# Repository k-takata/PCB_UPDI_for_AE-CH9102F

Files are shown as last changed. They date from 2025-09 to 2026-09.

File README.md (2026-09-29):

# UPDI Adapter for AE-CH9102F (Rev. 2)

## 概要

[秋月電子](https://akizukidenshi.com/)の[CH9102F USBシリアル変換モジュールキット Type-C (AE-CH9102F-TYPEC-BO)](https://akizukidenshi.com/catalog/g/g129505/)を、AVRマイコンのUPDI (Unified Program and Debug Interface)書き込み装置として使うためのアダプターです。

UPDI書き込みモードとシリアル通信モードは自動的に切り替わります。(Rev. 2)

UPDI部分の回路は[SerialUPDI](https://github.com/SpenceKonde/AVR-Guidance/blob/master/UPDI/jtag2updi.md)の "No resistor on target OR adapter" の回路を元に、RTS信号による自動切り替え機能を追加してあります。

注: 本アダプターは高電圧(HV)プログラミングには対応していません。HVプログラミングが必要な場合は、関連プロジェクトの[UPDI Unbricker](https://github.com/k-takata/PCB_updi_unbricker)を参照してください。

## 使用したソフトウェア

KiCad 9.0

## 回路図

Rev. 2  
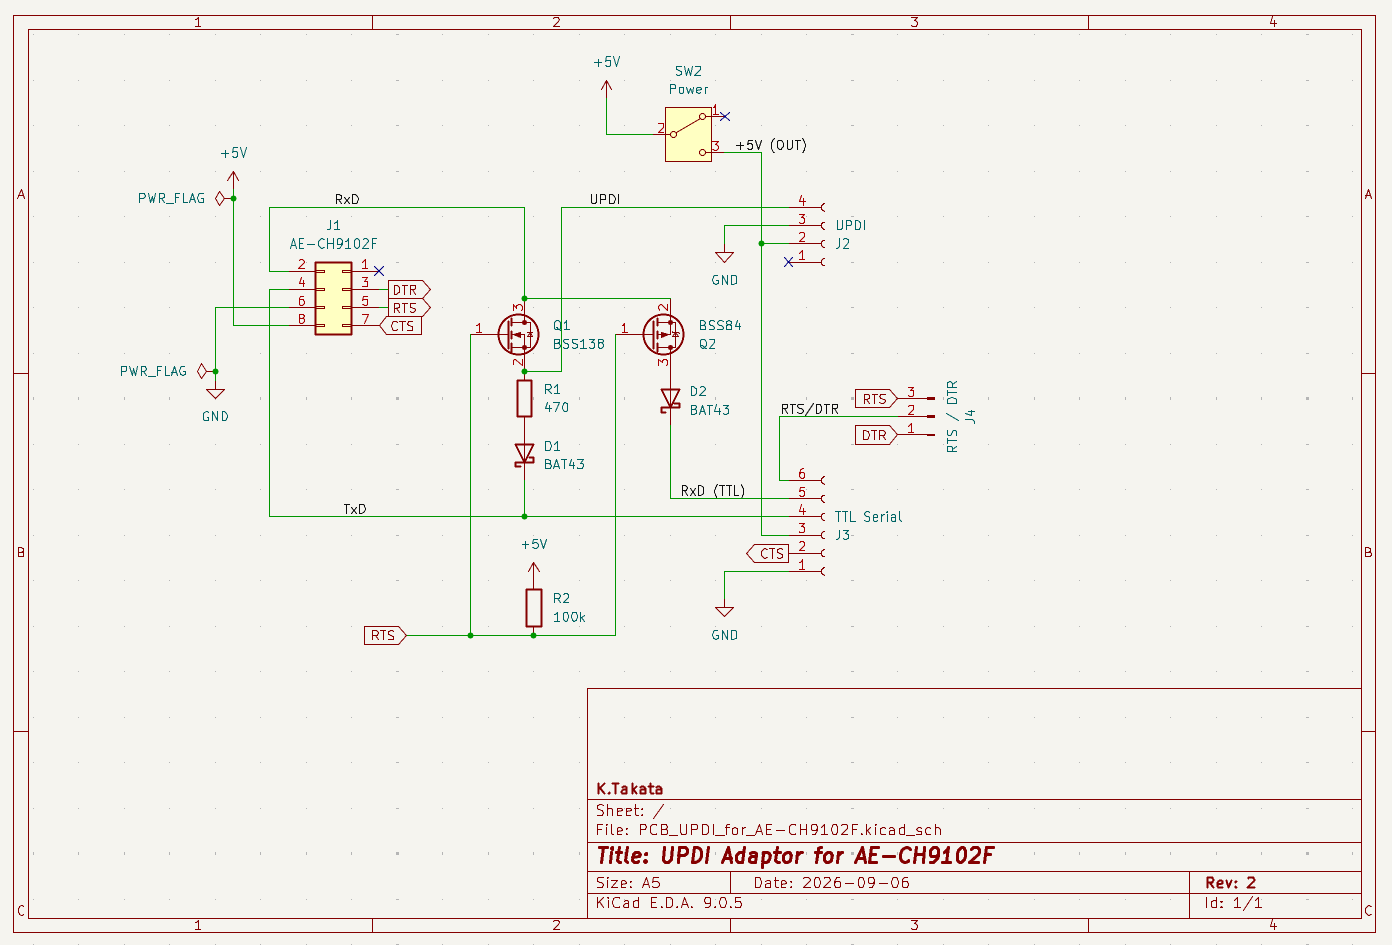
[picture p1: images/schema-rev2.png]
schema


## 基板パターン図

Rev. 2  
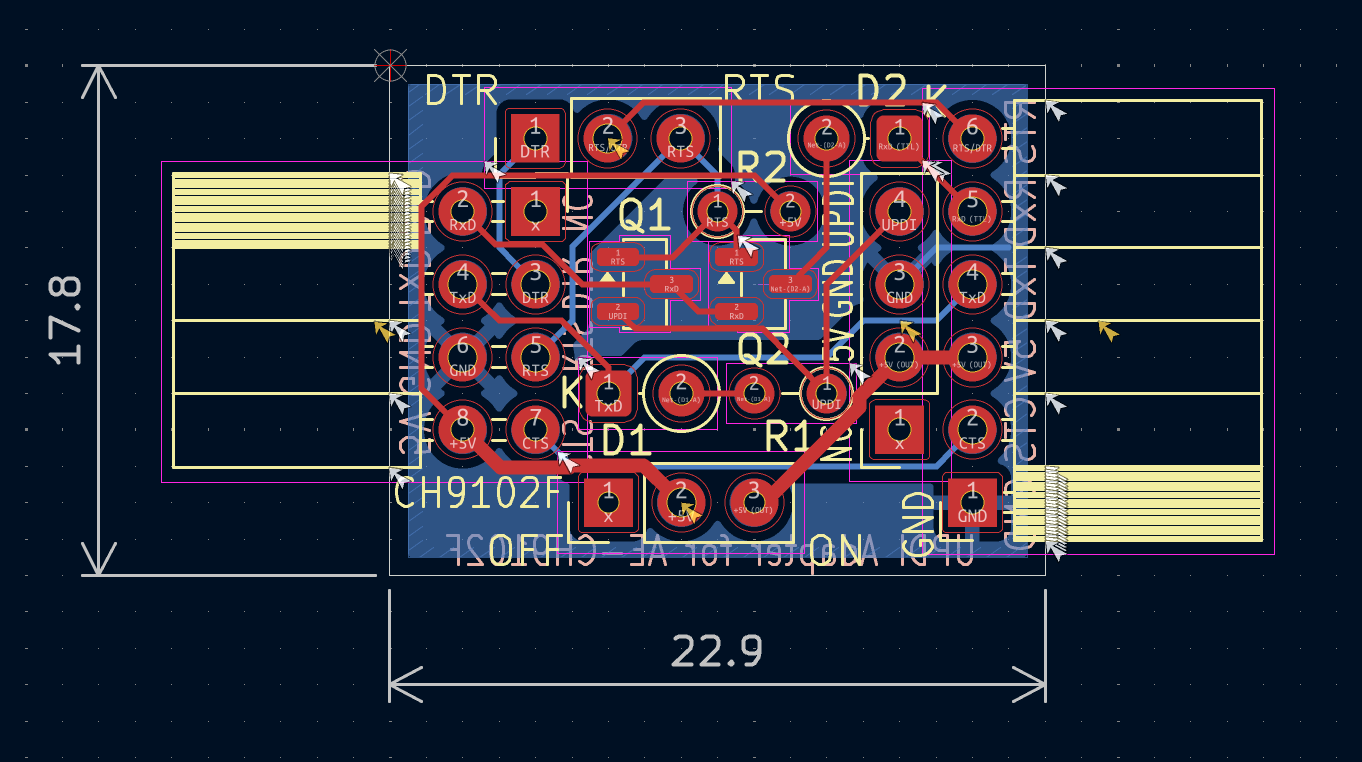
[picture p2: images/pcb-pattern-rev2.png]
PCB pattern


## 部品表

| Reference |個数|値 | 説明 |
|---|----|---|---|
|D1,D2 | 2|[BAT43](https://akizukidenshi.com/catalog/g/g113907/)|適当なショットキーバリアダイオード (他の例: [SD103A](https://akizukidenshi.com/catalog/g/g104271), [11EQS03L](https://akizukidenshi.com/catalog/g/g108997/))|
|J1 | 1| |L型ピンソケット 2x4 (\*1)、AE-CH9102F-TYPEC-BO接続用 |
|J2 | 1| |ピンソケット 1x4、UPDI接続用|
|J3 | 1| |[L型ピンソケット 1x6](https://akizukidenshi.com/catalog/g/g109862/)、TTL Serial接続用|
|J4 | 1| |ピンヘッダー 1x3、RTS/DTR切り替え用|
|Q1 | 1|[BSS138](https://akizukidenshi.com/catalog/g/g104232/)|Nch MOSFET|
|Q2 | 1|[BSS84](https://akizukidenshi.com/catalog/g/g104269)|Pch MOSFET|
|R1 | 1|470Ω |黄紫茶金、1/6Wサイズ(または1/4Wサイズ)|
|R2 | 1|100kΩ|茶黒黄金、1/6Wサイズ(または1/4Wサイズ)|
|SW1 | 1|[SS-12D00G3](https://akizukidenshi.com/catalog/g/g115707/)|スライドスイッチ 1回路2接点 基板用|

(\*1) 例えば、[L型ピンソケット 2x6](https://akizukidenshi.com/catalog/g/g116795/) (1個分)や[L型ピンソケット 2x15](https://akizukidenshi.com/catalog/g/g113419/) (3個分)などを加工して使用する。  

## 使用方法

J1をAE-CH9102F-TYPEC-BOと接続します。AE-CH9102F-TYPEC-BOには付属のピンヘッダーではなく、L型ピンヘッダー 2x4を基板表面側に取り付けておきます。

J2は、[AVR Programming Adapter](https://www.microchip.com/en-us/development-tool/AC31S18A)と同じUPDI v2コネクターとなっています。
ただし、1番ピンのRESETは未接続です。(高電圧プログラミングには対応していません。)

| Pin | 機能 | 色 |
|-----|---|----|
| 1 | RESET (NC) | 白 |
| 2 | VDD (5V) | 赤 |
| 3 | GND | 黒 |
| 4 | UPDI | 緑 |

J3は、一般的な6pinのTTLシリアルコネクターとなっています。6番ピンはJ4にジャンパーピンを挿すことでRTSかDTRのどちらかを選択できます。

| Pin | 機能 | 色 |
|-----|---|----|
| 1 | GND | 黒 |
| 2 | CTS | 茶 |
| 3 | VDD (5V) | 赤 |
| 4 | TxD | 橙 |
| 5 | RxD | 黄 |
| 6 | RTS / DTR  | 緑 |

SW1は、本アダプターから5Vを供給するかどうかを選択します。シルクのONの側に倒すと5Vを供給し、OFFの側に倒すと供給しません。マイコンに対して別の経路で電源を供給済みの場合はOFFにしてください。

UPDI書き込みモードとシリアル通信モードは自動的に切り替わります。
RTSがアクティブ(Low)の場合、シリアル通信モードとなり、そうでなければUPDIモードとなります。

Rev. 1では切り替え回路を単純にするため、2回路2接点スイッチではなく、1回路2接点スイッチを使用し、TxD側は接続したままとし、RxD側のみ（つまりAVRから送信する側）を切り替えるようにしていました。Rev. 2ではそれを発展させ、Nch MOSFET, Pch MOSFET, ショットキー・ダイオード（と追加のプルアップ抵抗）のみで自動切り替えを実現しています。 (先行事例としては、4052などのアナログスイッチICで2回路2接点スイッチを構成する例が多いようです。)  
Rev. 1ではUPDIデータ線はRxDと直結していましたが、Rev. 2ではQ1を介すように変更しています。Rev. 1の接続では、シリアル通信モードでAVRから送信したデータがUPDIにも届くため、通信内容によっては誤動作の可能性がありました。

Q2はPch MOSFETを使ってRTS信号で直接制御していますが、Nch MOSFETを使うようにした方が安定するかもしれません。その場合、RTS信号を反転する必要があるので、もう1つNch MOSFETと抵抗が必要になってしまいますが。

## 変更差分

Rev. 2での変更点は以下の通りです。

* スイッチによるUPDIモードとシリアル通信モードの手動切り替えを廃止し、RTS信号による自動切り替え機能を搭載。
* シルクを微調整。

## 完成品

Rev. 1  
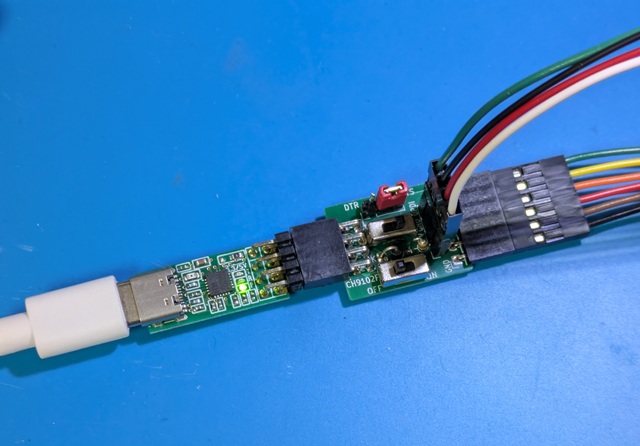
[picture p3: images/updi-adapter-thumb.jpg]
完成品


Rev. 2  
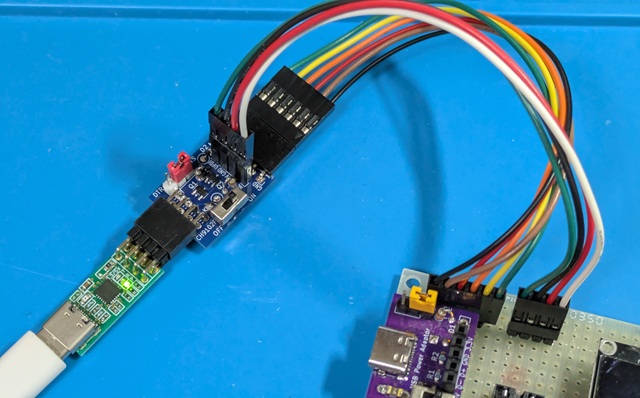
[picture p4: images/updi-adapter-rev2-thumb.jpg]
完成品 Rev. 2


## License

CC0

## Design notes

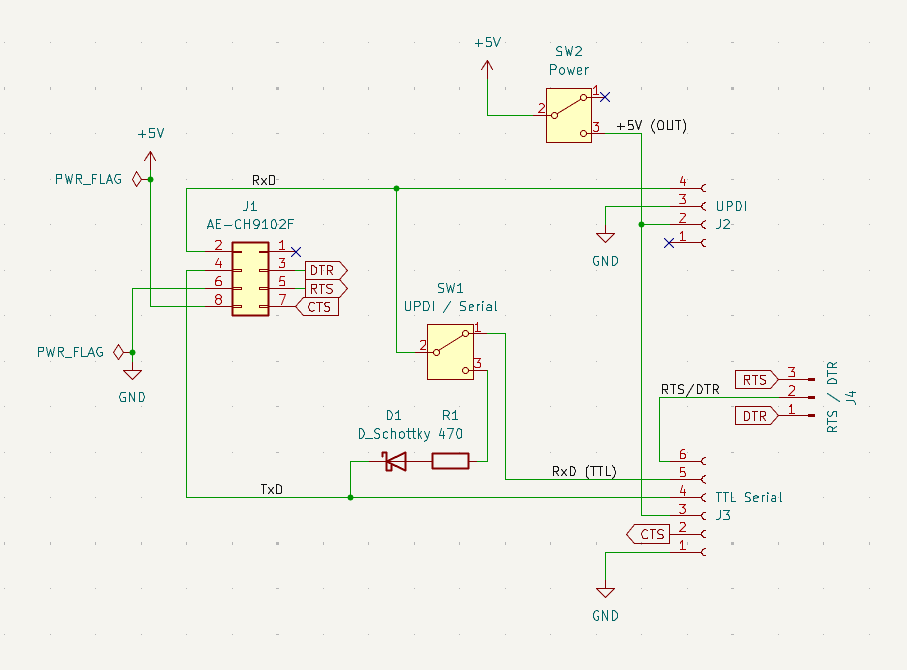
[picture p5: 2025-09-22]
images/schema.png

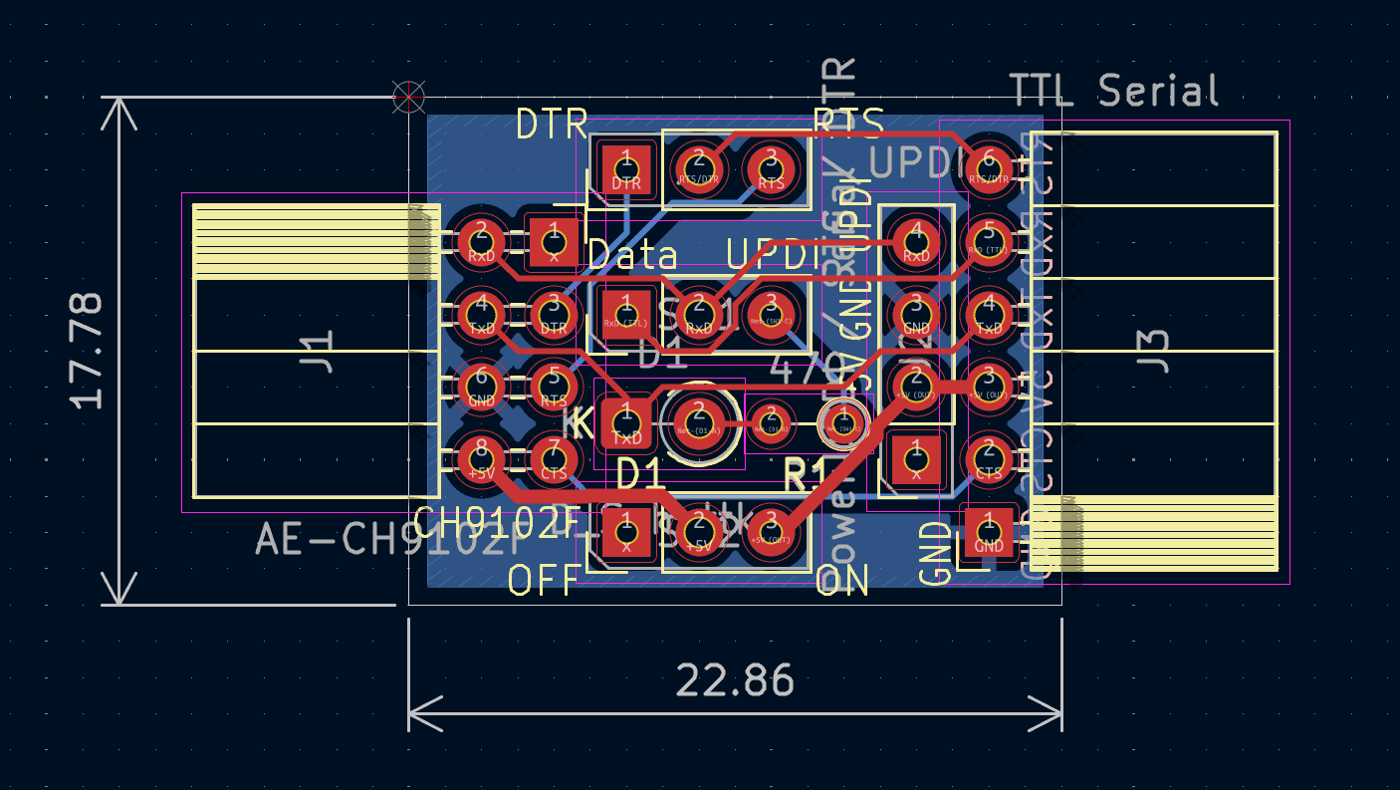
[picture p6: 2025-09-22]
images/pcb-pattern.png

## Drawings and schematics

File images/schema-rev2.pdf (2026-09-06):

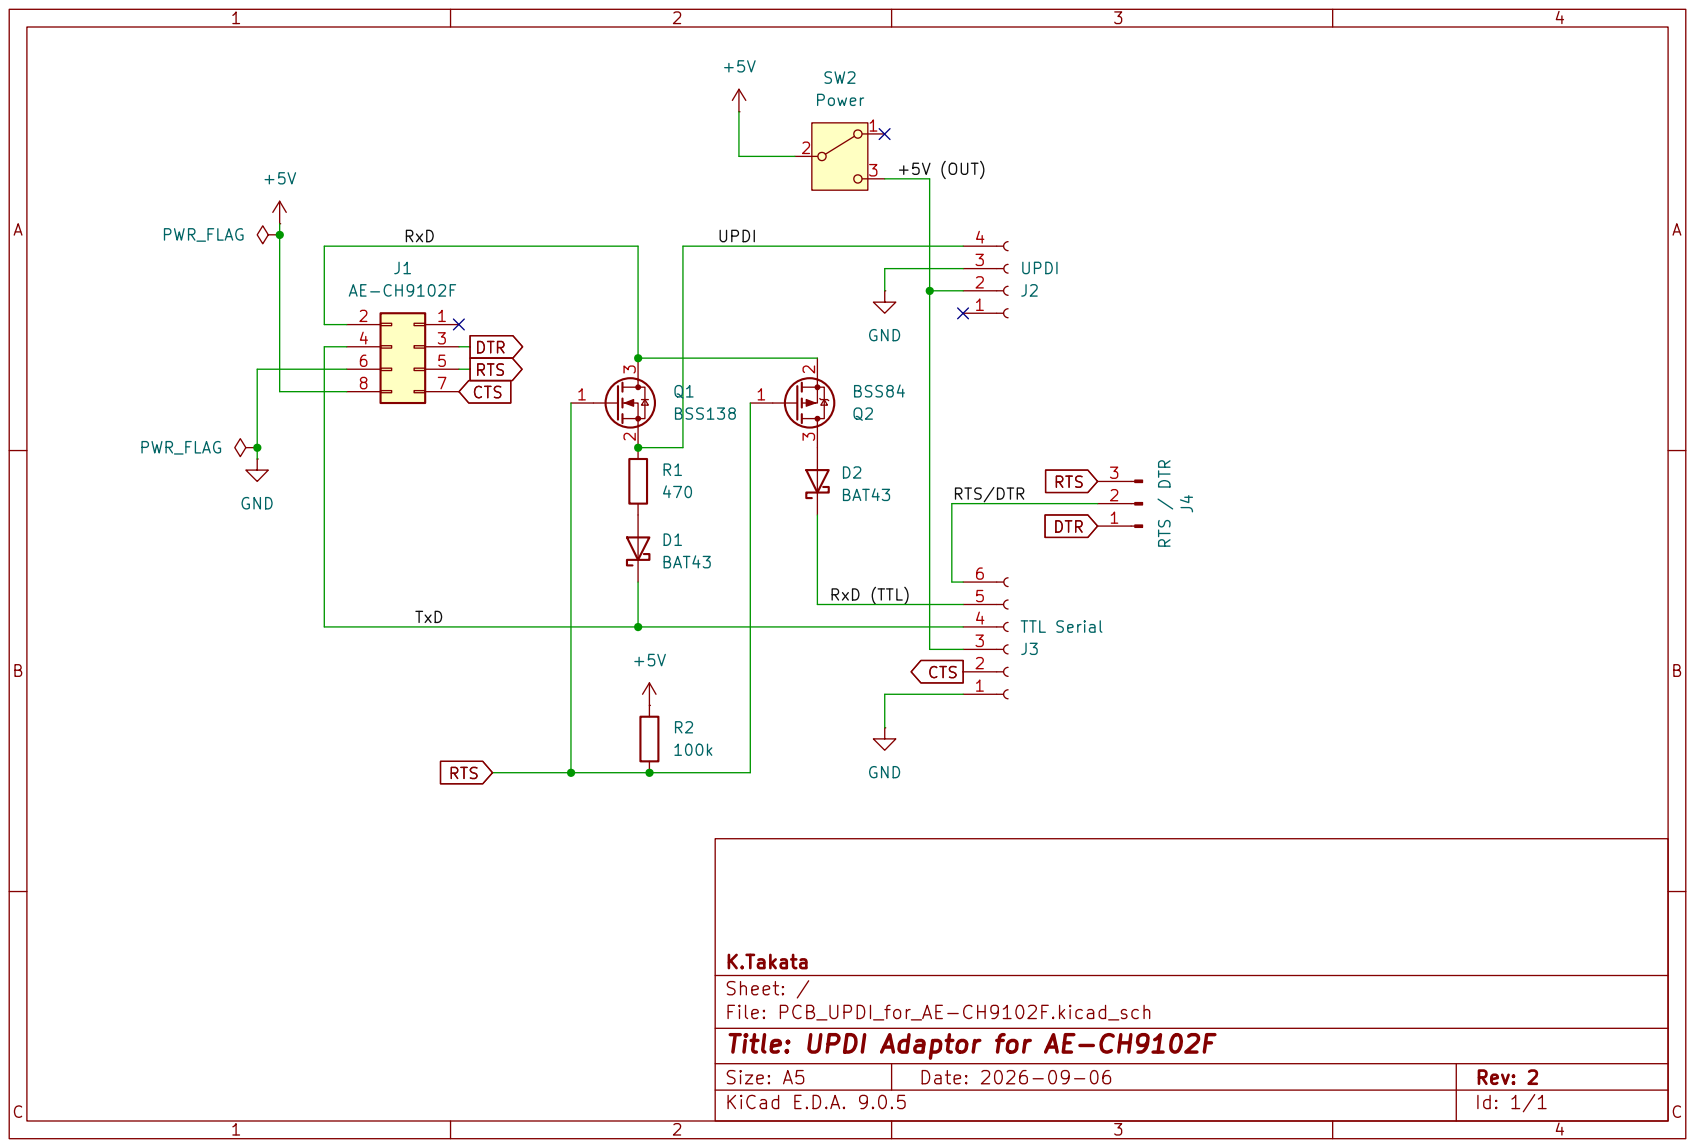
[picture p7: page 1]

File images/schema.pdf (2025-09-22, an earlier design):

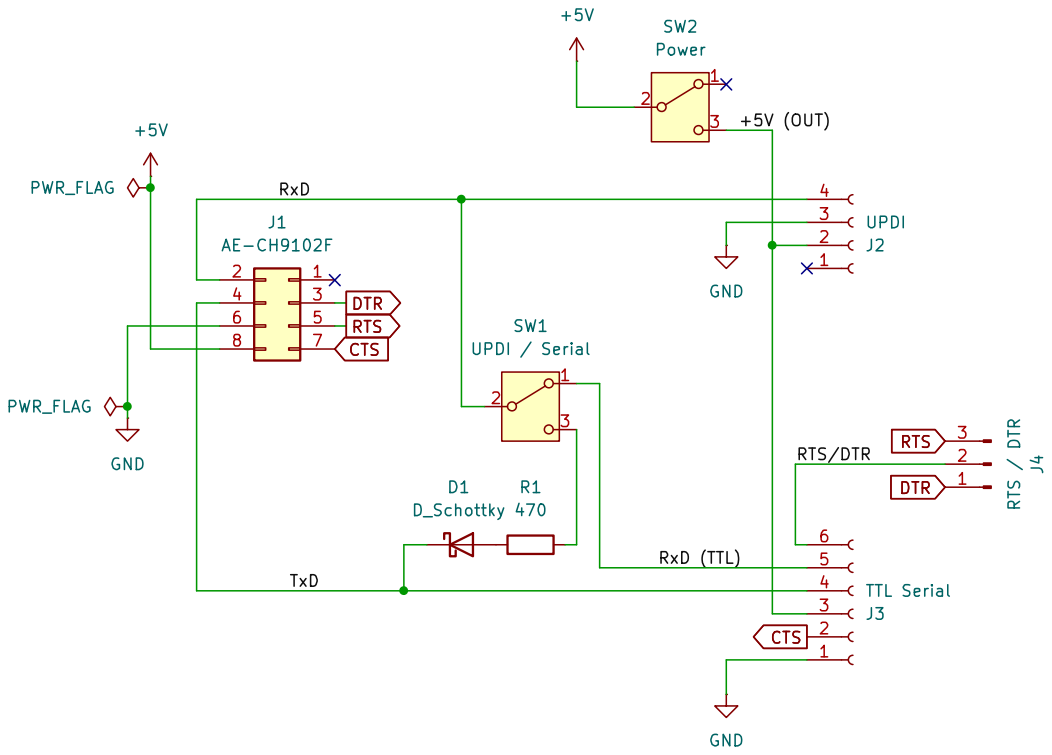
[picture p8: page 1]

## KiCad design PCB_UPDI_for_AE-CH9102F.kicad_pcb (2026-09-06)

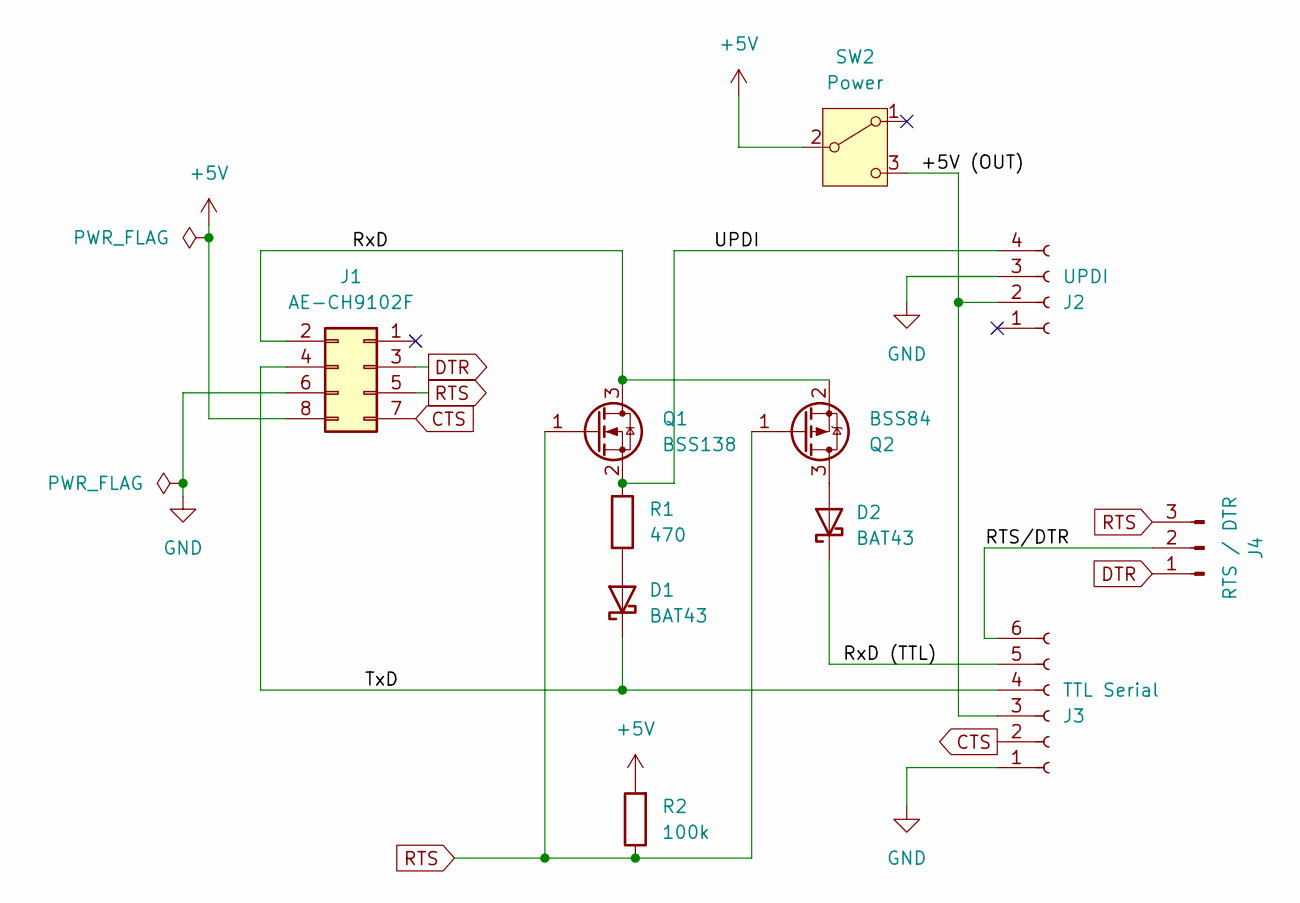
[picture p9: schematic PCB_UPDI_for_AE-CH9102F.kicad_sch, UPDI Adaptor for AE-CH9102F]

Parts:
D1, D2: BAT43; D_DO-35_SOD27_P2.54mm_Vertical_KathodeUp
J1: AE-CH9102F; PinSocket_2x04_P2.54mm_Horizontal
J2: UPDI; PinSocket_1x04_P2.54mm_Vertical
J3: TTL Serial; PinSocket_1x06_P2.54mm_Horizontal
J4: RTS / DTR; PinHeader_1x03_P2.54mm_Vertical
Q1: BSS138; SOT-23
Q2: BSS84; SOT-23
R1: 470; R_Axial_DIN0204_L3.6mm_D1.6mm_P2.54mm_Vertical
R2: 100k; R_Axial_DIN0204_L3.6mm_D1.6mm_P2.54mm_Vertical
SW2: Power; PinHeader_1x03_P2.54mm_Vertical

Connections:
+5V: J1.8, R2.2, SW2.2 (B)
/+5V (OUT): J2.2, J3.3, SW2.3 (C)
/RTS/DTR: J3.6, J4.2
/RxD: J1.2, Q1.3 (D), Q2.2 (S)
/RxD (TTL): D2.1 (K), J3.5
/TxD: D1.1 (K), J1.4, J3.4
/UPDI: J2.4, Q1.2 (S), R1.1
CTS: J1.7, J3.2
DTR: J1.3, J4.1
GND: J1.6, J2.3, J3.1
unnamed: D1.2 (A), R1.2
unnamed: D2.2 (A), Q2.3 (D)
RTS: J1.5, J4.3, Q1.1 (G), Q2.1 (G), R2.1

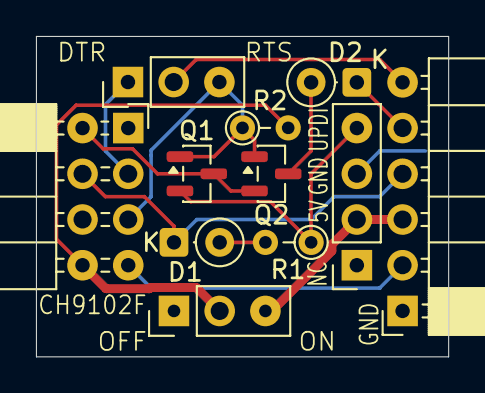
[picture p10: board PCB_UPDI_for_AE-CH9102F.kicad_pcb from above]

Board: 2 copper layers, 22.9 x 17.8 mm, 11 parts (0 on the bottom side), 13 nets.

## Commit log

2025-09-22 Initial version
    [PCB_UPDI_for_AE-CH9102F.kicad_pcb, PCB_UPDI_for_AE-CH9102F.kicad_sch]
2025-09-22 Update back silk
    [PCB_UPDI_for_AE-CH9102F.kicad_pcb]
2025-11-17 Update J1 connection instructions in README
    Clarify installation instructions for L-shaped pin header.
2026-09-06 Rev. 2
    Implement auto switching between the UPDI mode and the UART mode.
    [PCB_UPDI_for_AE-CH9102F.kicad_pcb, PCB_UPDI_for_AE-CH9102F.kicad_sch]
2026-09-07 Update README with corrected analog switch reference
    Corrected the reference from '4066' to '4052' in the explanation of the switching circuit.
2026-09-09 Update README with a note about Rev. 2 changes
    Rev. 2 introduces automatic switching using Nch and Pch MOSFETs, improving circuit design. It also modifies the UPDI data line connection to enhance communication stability.
    However, there is a concern about using a Pch MOSFET.
    Write a note about that.
2026-09-29 Add HV programming note and reference in README
    Added note about high voltage programming limitations and reference to UPDI Unbricker project.
2026-10-04 Update for Rev. 3
    * Use 74LVC1G3157.
    * Use SMD devices.
    [PCB_UPDI_for_AE-CH9102F.kicad_pcb, PCB_UPDI_for_AE-CH9102F.kicad_sch]
2026-10-06 Change schematic link to relative path
    Updated the link for the schematic image to a relative path.
2026-10-07 Clarify U1 component description in README
    Updated description for U1 component in the BOM.
